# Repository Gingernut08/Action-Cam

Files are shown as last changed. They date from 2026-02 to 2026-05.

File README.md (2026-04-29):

This project is a compact, DIY camera system built using an ESP32-CAM, designed specifically for use while kayaking. It captures photos or short video clips and stores them locally on a microSD card, keeping the setup simple and self-contained. The focus is on low power use, minimal size, and reliability in a splash-prone environment rather than high-end video quality. Housed in a sealed enclosure and powered by a battery, it’s meant to be mounted on a kayak to document trips, conditions, and moments on the water in a lightweight way.

All componants will be hot glued into place including a ESP32-CAM, LiPo Battery, LED indicaator and Toggle switch. Full case will be coated in epoxy resin to seal against water



Full Case and mount



Screw in back plate with TPU seal



Wiring Diagram

BOM

|Item|Number|Price|Link|
|---|---|---|---|
|Toggle Switch|1|1.35|https://www.aliexpress.com/item/1005008914707882.html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|
|LIPO charger|1|4.21|https://www.aliexpress.com/item/1005002840620562.html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
|MOSFET|1|1.83|https://www.aliexpress.com/item/1005005066145203.html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|
|Epoxy Resin|2|2.3|https://www.aliexpress.com/item/1005007115129874.html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|
|PH2.0 connector|3|1.7|https://www.aliexpress.com/item/1005007270514533.html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|
150 ohm resistor|1|1.18|https://www.aliexpress.com/item/1005006919048375.html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|
|Voltage step up|1|1.95|https://www.aliexpress.com/item/1005010399811030.html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|
|ESP32 CAM|1|6.59|https://www.aliexpress.com/item/1005007003821969.html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|
|103450 LIPO|1|0.99|https://www.aliexpress.com/item/1005009590723370.html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|
3D printed case top / bottom|1||

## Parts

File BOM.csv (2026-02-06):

Item | Number | Price | Link
Toggle Switch | 1 | 1.35 | https://www.aliexpress.com/item/1005008914707882.html?mp=1
LIPO charger | 1 | 4.21 | https://www.aliexpress.com/item/1005002840620562.html?mp=1
MOSFET | 1 | 1.83 | https://www.aliexpress.com/item/1005005066145203.html?mp=1
Epoxy Resin | 2 | 2.3 | https://www.aliexpress.com/item/1005007115129874.html?mp=1
PH2.0 connector | 3 | 1.7 | https://www.aliexpress.com/item/1005007270514533.html?mp=1
150 ohm resistor | 1 | 1.18 | https://www.aliexpress.com/item/1005006919048375.html?mp=1
Voltage step up | 1 | 1.95 | https://www.aliexpress.com/item/1005010399811030.html?mp=1
ESP32 CAM | 1 | 6.59 | https://www.aliexpress.com/item/1005007003821969.html?mp=1
103450 LIPO | 1 | 0.99 | https://www.aliexpress.com/item/1005009590723370.html?mp=1
3D printed case top / bottom | 1

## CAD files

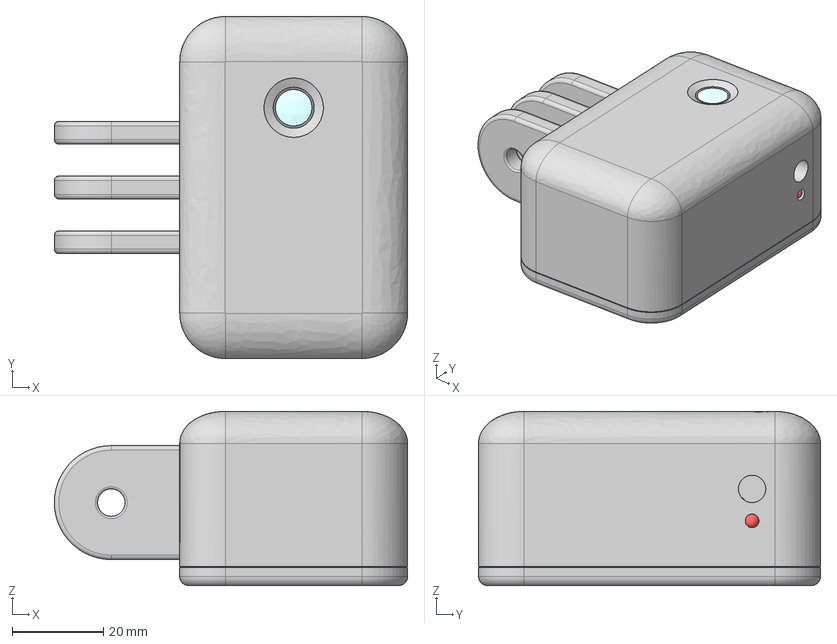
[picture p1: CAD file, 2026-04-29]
CAD/Main.step
77.5 x 75.0 x 38.2 mm
Batery
OV2640_21mm-160_camera
Case
LED

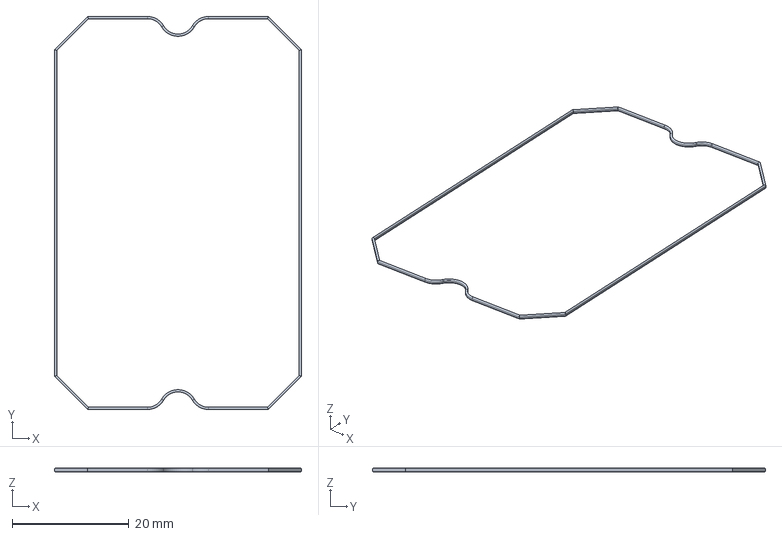
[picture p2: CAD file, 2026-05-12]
CAD/TPU Seal.step
42.3 x 67.3 x 0.7 mm

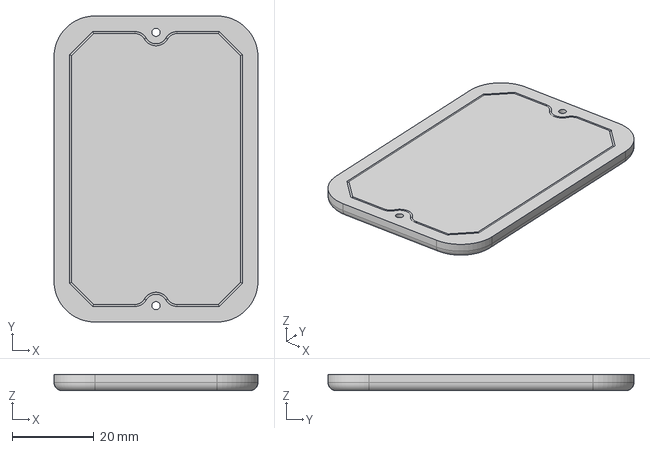
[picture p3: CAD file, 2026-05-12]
CAD/Cover.step
50.0 x 75.0 x 4.00 mm

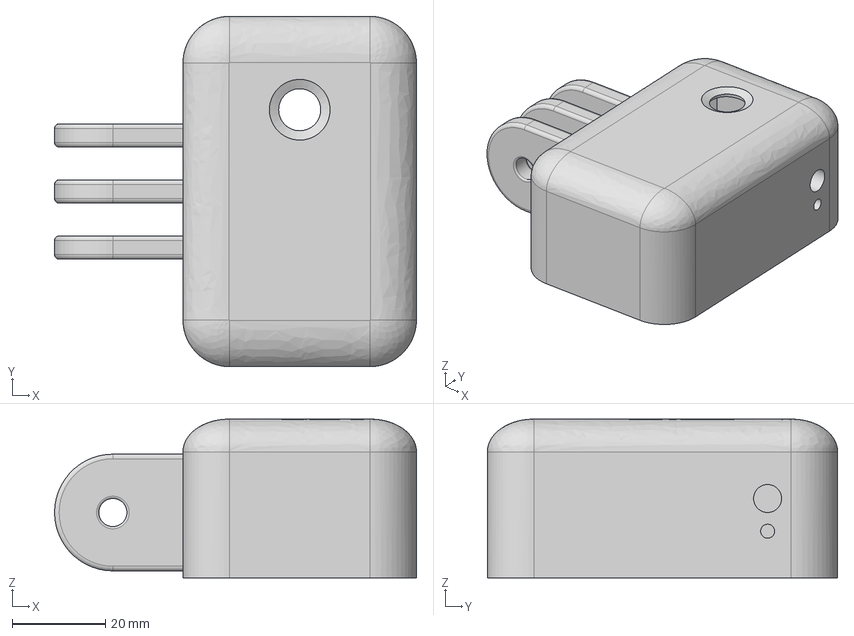
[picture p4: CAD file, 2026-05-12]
CAD/Shell.step
77.5 x 75.0 x 34.0 mm

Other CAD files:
CAD/Main.f3z

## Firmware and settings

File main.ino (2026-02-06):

#include "esp_camera.h"
#include "FS.h"
#include "SD_MMC.h"

#define PWDN_GPIO_NUM     32
#define RESET_GPIO_NUM    -1
#define XCLK_GPIO_NUM      0
#define SIOD_GPIO_NUM     26
#define SIOC_GPIO_NUM     27

#define Y9_GPIO_NUM       35
#define Y8_GPIO_NUM       34
#define Y7_GPIO_NUM       39
#define Y6_GPIO_NUM       36
#define Y5_GPIO_NUM       21
#define Y4_GPIO_NUM       19
#define Y3_GPIO_NUM       18
#define Y2_GPIO_NUM        5
#define VSYNC_GPIO_NUM    25
#define HREF_GPIO_NUM     23
#define PCLK_GPIO_NUM     22

#define RECORD_SWITCH_GPIO 1   // switch to GND (INPUT_PULLUP)
#define RECORD_LED_GPIO    3   // MOSFET gate (HIGH = LED ON)

bool recording = false;
int frameNumber = 0;

void setup() {
  // Serial disabled: GPIO 1 & 3 used
  // Serial.begin(115200);

  pinMode(RECORD_SWITCH_GPIO, INPUT_PULLUP);

  pinMode(RECORD_LED_GPIO, OUTPUT);
  digitalWrite(RECORD_LED_GPIO, LOW);   // MOSFET OFF at boot

  // Camera configuration
  camera_config_t config;
  config.ledc_channel = LEDC_CHANNEL_0;   config.ledc_timer   = LEDC_TIMER_0;   config.pin_d0       = Y2_GPIO_NUM;
  config.pin_d1       = Y3_GPIO_NUM;      config.pin_d2       = Y4_GPIO_NUM;    config.pin_d3       = Y5_GPIO_NUM;
  config.pin_d4       = Y6_GPIO_NUM;      config.pin_d5       = Y7_GPIO_NUM;    config.pin_d6       = Y8_GPIO_NUM;
  config.pin_d7       = Y9_GPIO_NUM;      config.pin_xclk     = XCLK_GPIO_NUM;  config.pin_pclk     = PCLK_GPIO_NUM;
  config.pin_vsync    = VSYNC_GPIO_NUM;   config.pin_href     = HREF_GPIO_NUM;  config.pin_sscb_sda = SIOD_GPIO_NUM;
  config.pin_sscb_scl = SIOC_GPIO_NUM;    config.pin_pwdn     = PWDN_GPIO_NUM;  config.pin_reset    = RESET_GPIO_NUM;

  config.xclk_freq_hz = 20000000;
  config.pixel_format = PIXFORMAT_JPEG;

  config.frame_size   = FRAMESIZE_QVGA; // 320x240
  config.jpeg_quality = 12;
  config.fb_count     = 2;

  esp_camera_init(&config);
  SD_MMC.begin();
}

void loop() {
  bool switchPressed = (digitalRead(RECORD_SWITCH_GPIO) == LOW);

  if (switchPressed && !recording) {
    recording = true;
    frameNumber = 0;
    digitalWrite(RECORD_LED_GPIO, HIGH); // MOSFET ON
  }

  if (!switchPressed && recording) {
    recording = false;
    digitalWrite(RECORD_LED_GPIO, LOW);  // MOSFET OFF
  }

  if (!recording) {
    delay(50);
    return;
  }

  camera_fb_t *fb = esp_camera_fb_get();
  if (!fb) return;

  char path[32];
  sprintf(path, "/vid_%05d.jpg", frameNumber++);

  File file = SD_MMC.open(path, FILE_WRITE);
  if (file) {
    file.write(fb->buf, fb->len);
    file.close();
  }

  esp_camera_fb_return(fb);

  delay(80); // ~12 FPS
}

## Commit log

2026-02-06 Add initial schematic file for filepath
2026-02-06 Add BOM section to README
    Added a Bill of Materials (BOM) section with item details.
